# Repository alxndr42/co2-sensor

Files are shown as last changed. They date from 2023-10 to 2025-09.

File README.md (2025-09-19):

# co2-sensor

Low-cost headless CO2 sensor, based on [ESPHome](https://esphome.io/).

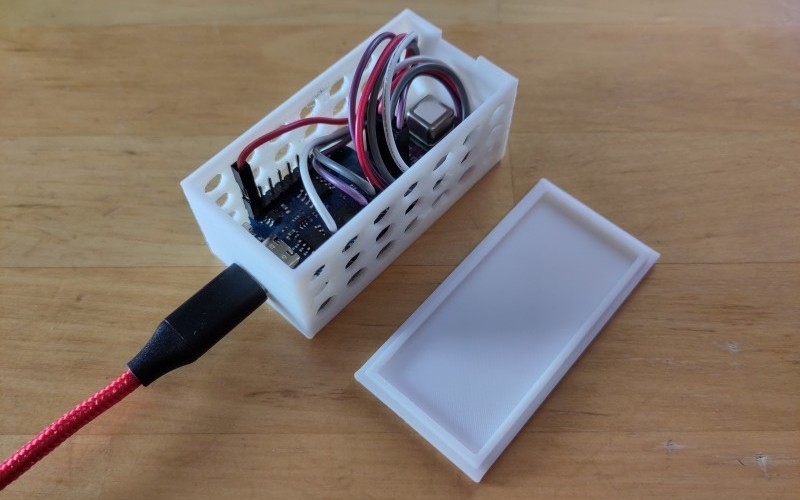
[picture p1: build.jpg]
Photo of an assembled CO2 sensor with the lid removed, powered by USB-C cable


Grafana and HTML dashboards included.

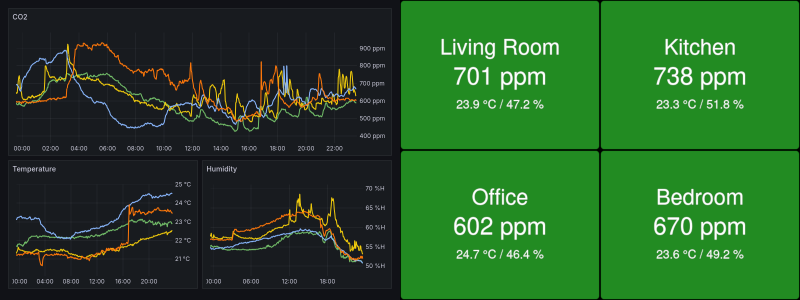
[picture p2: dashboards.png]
Screenshots of Grafana and HTML dashboards


## Components

The included [config.yaml](config.yaml) uses the following components:

- Wemos [D1 mini][] board (or clone). (Cost: ca. 2 EUR)
- Sensirion [SCD4x][] CO2 sensor module. (Cost: ca. 15 EUR)

Connecting the boards will require some soldering, and the type of wire you would like to use.

The [case](case) folder contains STL files and their [OpenSCAD][] sources for a simple 3D-printed case.

[d1 mini]: https://www.wemos.cc/en/latest/d1/d1_mini.html
[openscad]: https://openscad.org/
[scd4x]: https://developer.sensirion.com/sensirion-products/scd4x-co2-sensors/

## Assembly

Connect the D1 Mini board and CO2 sensor module as follows:

| D1 Mini Pin | CO2 Sensor Pin |
| --- | --- |
| GND | GND |
| 3V3 | VDD |
| SCL | SCL |
| SDA | SDA |

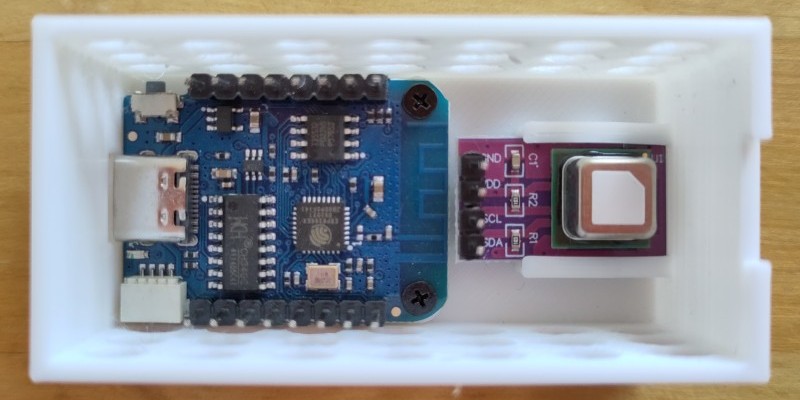
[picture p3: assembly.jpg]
Photo of both boards mounted in a 3D-printed case


Short M2 screws (~3 mm) should work for the D1 mini board. The sensor module can simply be pushed into its holder.

## Firmware Installation

Connect the D1 Mini board to your computer via USB for the initial firmware installation.

```bash
# Create (then customize) secrets.yaml
cp secrets-example.yaml secrets.yaml
# Install firmware with standard configuration
esphome run config.yaml --no-logs
# Install firmware with custom device name
esphome -s name co2sensor42 run config.yaml --no-logs
```

After connecting to your Wifi network, the ESPHome web interface should be available at http://co2sensor (or your custom device name).

## Monitoring

Prometheus metrics should be available at http://co2sensor/metrics (or your custom device name).

The [grafana](grafana) folder contains example Grafana dashboards.

The [hackydash](hackydash) folder contains a simple HTML dashboard.

## Sensor Calibration

By default, the SCD4x performs `Automatic Self-Calibration` (ASC), and does not need to be calibrated manually. However, the data sheet contains this note:

> The automatic self-calibration algorithm assumes that the sensor is exposed to the atmospheric CO2 concentration of 400 ppm at least once per week.

If sufficient ventilation cannot be ensured, it might become necessary to perform `Forced Recalibration` (FRC) using a reference value. The ESPHome web interface contains an `FRC` button for performing the calibration, and an `FRC Reference` slider for setting the reference value. Before calibration, the data sheet suggests:

> Operate the SCD4x in the operation mode later used in normal sensor operation (periodic measurement, low power periodic measurement or single shot) for > 3 minutes in an environment with homogenous and constant CO2 concentration.

The FRC functionality can be disabled by setting the variable `frc` to `disabled`.

---

Trans Rights are Human Rights! 🏳️‍⚧️ 🏳️‍🌈

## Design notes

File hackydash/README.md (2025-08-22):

# HTML Dashboard

The HTML dashboard shows "traffic light" style panels for each sensor:

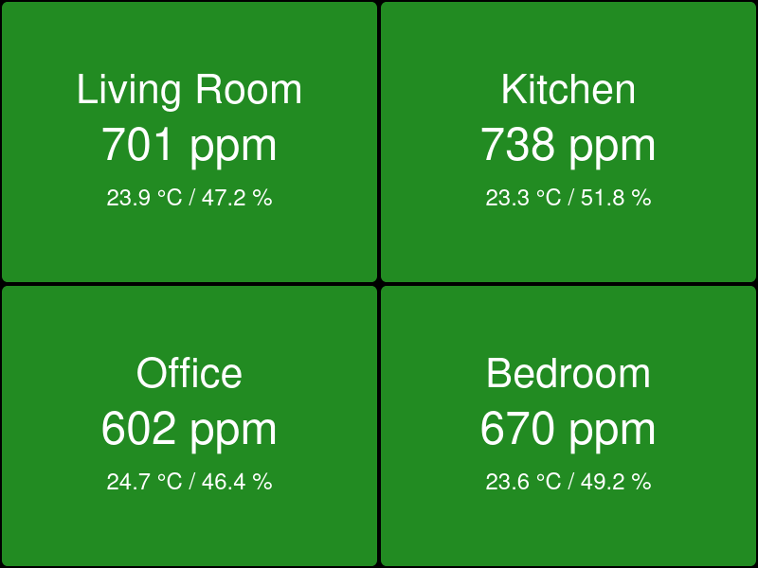
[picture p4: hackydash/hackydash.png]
Screenshot of the HTML dashboard


The display of temperature and humidity can be disabled in the config file.

Usage:

1. Copy `config-example.json` to `config.json` and add your sensors.
1. Add your own CSS as `custom.css`. (Optional)
1. Serve the files via HTTP.
   (For example, run `python3 -m http.server --bind localhost` and open <http://localhost:8000>.)

Depending on your web browser, you may need to disable HTTPS-Only mode for the
dashboard URL, the sensor URLs, or both.

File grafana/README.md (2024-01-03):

# Grafana Dashboards

## CO2 Levels

The `CO2 Levels` dashboard shows "traffic light" style panels for each sensor:

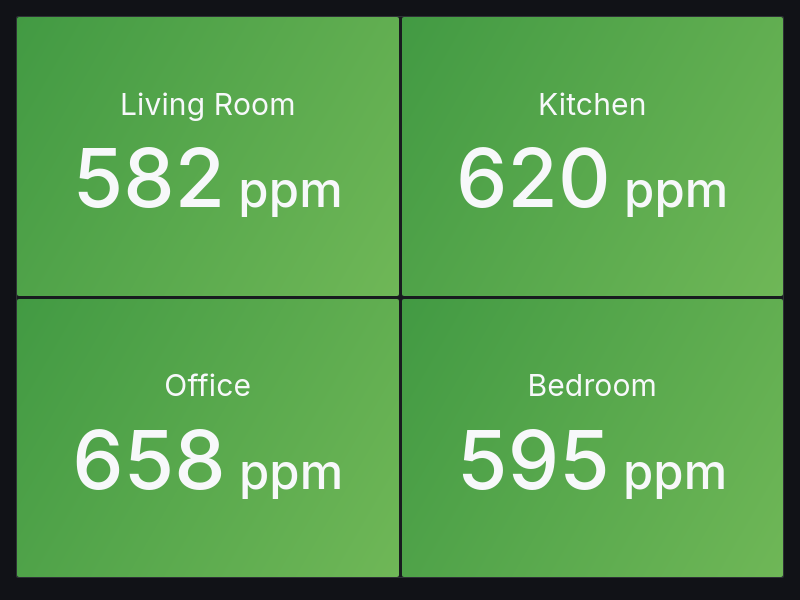
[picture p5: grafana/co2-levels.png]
Screenshot of the CO2 Levels dashboard


The dashboard in the screenshot has been modified to use a `location` label in the legend, which has been added via `prometheus.yml`:

```yaml
scrape_configs:
  - job_name: esphome
    # ...
    metric_relabel_configs:
      - source_labels: ["instance"]
        regex: "co2sensor01.*"
        replacement: "Living Room"
        target_label: "location"
      - source_labels: ["instance"]
        regex: "co2sensor02.*"
        replacement: "Kitchen"
        target_label: "location"
      - source_labels: ["instance"]
        regex: "co2sensor03.*"
        replacement: "Office"
        target_label: "location"
      - source_labels: ["instance"]
        regex: "co2sensor04.*"
        replacement: "Bedroom"
        target_label: "location"
```

## CO2 Sensors

The `CO2 Sensors` dashboard shows line charts for CO2, temperature, and humidity:

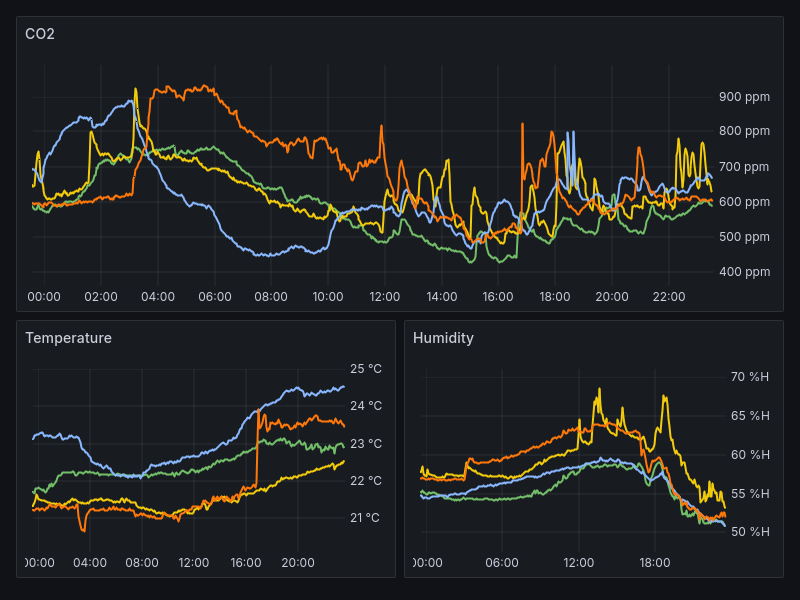
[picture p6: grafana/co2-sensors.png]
Screenshot of the CO2 Sensors dashboard


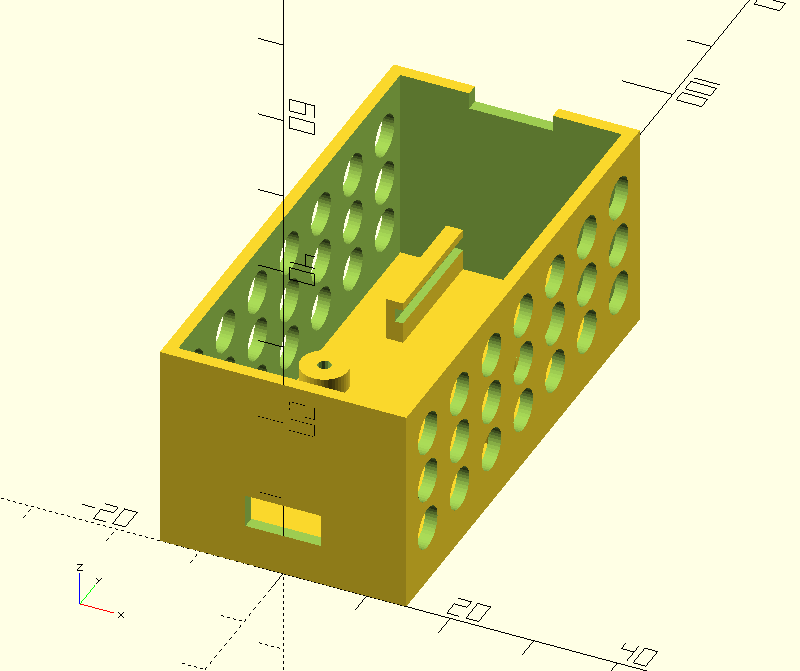
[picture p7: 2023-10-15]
case/base.png

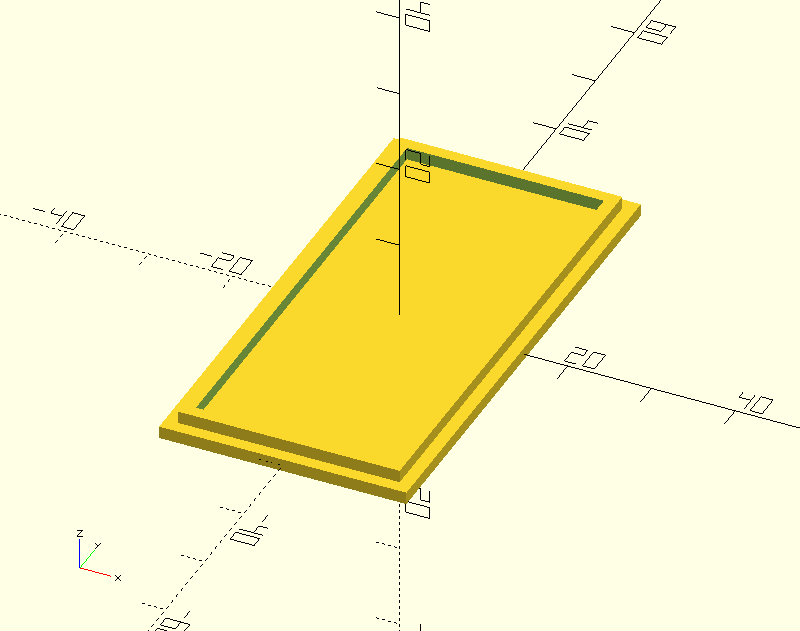
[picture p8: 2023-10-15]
case/lid.png

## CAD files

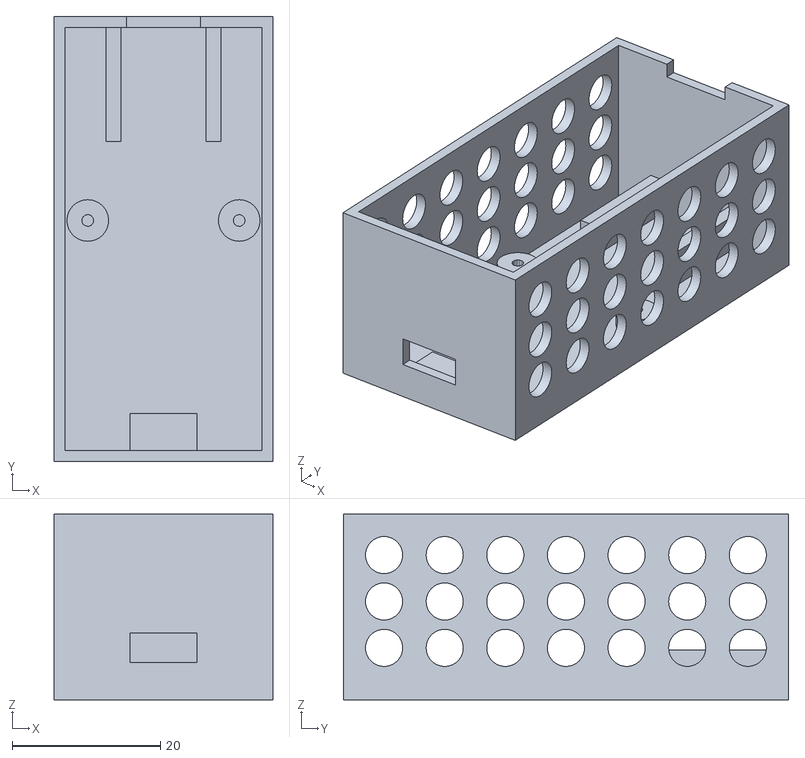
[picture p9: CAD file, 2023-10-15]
case/base.stl
29.5 x 60.0 x 25.0

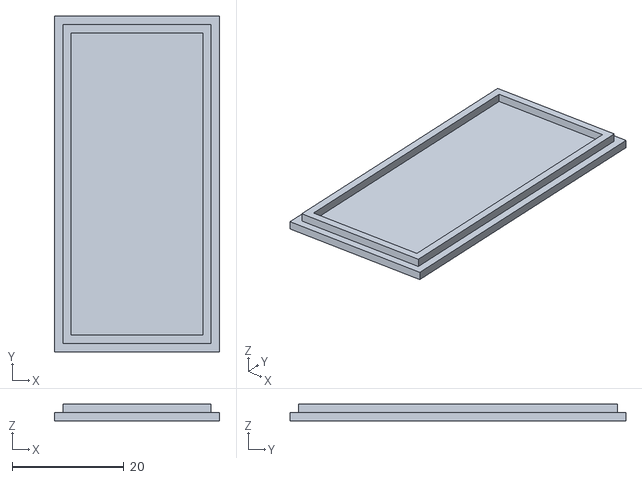
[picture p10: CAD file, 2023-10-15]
case/lid.stl
29.5 x 60.0 x 2.99

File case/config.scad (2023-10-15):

$fa = 1;
$fs = 0.4;

// ESP PCB dimensions (with margins)
esp_pcb_w = 26.5;
esp_pcb_l = 34.5;
esp_pcb_h = 1.0;

// SCD PCB dimensions (with margins)
scd_pcb_w = 13.5;
scd_pcb_l = 22.5;
scd_pcb_h = 1.7;

// ESP PCB foot height
foot_h = 2.5;
// ESP PCB surface height
surface_h = foot_h + esp_pcb_h;
// Component height above ESP PCB
component_h = 20;

// SCD PCB rail length
scd_rail_l = scd_pcb_l*0.75;

// Thickness of the sides
side_t = 1.5;
// Wall height without top/bottom sides
wall_h = surface_h + component_h;

// USB hole dimensions (with margins)
usb_hole_w = 9;
usb_hole_h = 4;

// Rear gap for removing the lid
gap_w = 10;
gap_h = 2;

// Total case dimensions
total_w = esp_pcb_w + side_t*2;
total_l = esp_pcb_l + scd_pcb_l + side_t*2;

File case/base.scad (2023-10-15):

include <config.scad>

// Bottom Side
translate([0, total_l/2, side_t/2])
    cube([total_w, total_l, side_t], center=true);

// Walls
translate([0, 0, side_t - 0.01])
    difference() {
        // Sides
        translate([0, total_l/2, wall_h/2])
            difference() {
                cube([total_w, total_l, wall_h], center=true);
                cube([total_w - side_t*2, total_l - side_t*2, wall_h*2], center=true);
                ventilation_holes(total_l, wall_h);
            }
        // USB Hole
        translate([0, side_t/2, usb_hole_h/2 + surface_h])
            cube([usb_hole_w, side_t*2, usb_hole_h], center=true);
        // Rear Gap
        translate([0, total_l - side_t/2, wall_h - gap_h/2 + 0.01])
            cube([gap_w, side_t*2, gap_h], center=true);
    }

// ESP Feet
translate([0, side_t, side_t - 0.01])
    esp_feet(usb_hole_w);

// SCD Rails
translate([0, total_l - scd_rail_l/2 + 0.01, side_t - 0.01]) {
    translate([scd_pcb_w/2, 0, 0])
        scd_rail(scd_rail_l);
    mirror([1, 0, 0])
        translate([scd_pcb_w/2, 0, 0])
            scd_rail(scd_rail_l);
}

//
// Modules
//

module ventilation_holes(wall_l, wall_h, hole_d=5, margin=side_t*2) {
    gap_v = (wall_h - margin*2 - hole_d*3)/2;

    ventilation_row(wall_l, margin, hole_d);
    translate([0, 0, hole_d + gap_v])
        ventilation_row(wall_l, margin, hole_d);
    translate([0, 0, -hole_d - gap_v])
        ventilation_row(wall_l, margin, hole_d);
}

module ventilation_row(length, margin, hole_d) {
    count = floor((length - margin*2) / (hole_d*1.5));
    gap = (length - margin*2 - hole_d*count) / (count - 1);

    for(i=[0:count-1]) {
        translate([0, -length/2 + hole_d/2 + margin + (hole_d + gap)*i, 0])
            rotate([0, 90, 0])
                cylinder(100, d=hole_d, center=true);
    }
}

module esp_feet(front_w, front_l=5) {
    screw_d = 1.6;
    screw_x = 10.2;
    screw_y = 31;
    rear_d = screw_d + 4;

    // Front Foot
    translate([0, front_l/2, foot_h/2])
        cube([front_w, front_l, foot_h], center=true);

    // Rear Left Foot
    translate([-screw_x, screw_y, foot_h/2])
        difference() {
            cylinder(h=foot_h, d=rear_d, center=true);
            cylinder(h=foot_h*2, d=screw_d, center=true);
        }

    // Rear Right Foot
    translate([screw_x, screw_y, foot_h/2])
        difference() {
            cylinder(h=foot_h, d=rear_d, center=true);
            cylinder(h=foot_h*2, d=screw_d, center=true);
        }
}

module scd_rail(length) {
    rail_w = 2;
    rail_h = foot_h + scd_pcb_h + 1;

    translate([0, 0, rail_h/2])
        difference() {
            cube([rail_w, length, rail_h], center=true);
            translate([-rail_w/4 - 0.01, 0, foot_h - scd_pcb_h])
                cube([rail_w/2, length*2, scd_pcb_h], center=true);
        }
}

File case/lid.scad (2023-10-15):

include <config.scad>

 // Top Side
cube([total_w, total_l, side_t], center=true);

// Rim
translate([0, 0, side_t - 0.01])
    difference() {
        cube([total_w - side_t*2, total_l - side_t*2, side_t], center=true);
        cube([total_w - side_t*4, total_l - side_t*4, side_t*2], center=true);
    }

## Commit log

2023-06-21 Add device name substitution, Prometheus endpoint
2023-07-08 Add Forced Recalibration button
2023-10-15 Add case files
    [base.scad, base.stl, config.scad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]
2025-08-22 Add temperature/humidity to hackydash
